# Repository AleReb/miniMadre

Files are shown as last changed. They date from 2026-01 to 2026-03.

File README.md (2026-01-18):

# miniMadre

**Placa de desarrollo basada en el trabajo de Sebastian Adonay con Alejandro Rebolledo.**

## Descripción del Proyecto

El objetivo de este proyecto es desarrollar una versión miniatura y flexible de una placa madre (*motherboard*) que también funcione como una placa para el **hiriPro**.

### Características Principales

*   **Versatilidad:** Diseñada para ser una solución miniatura y flexible.
*   **Integración ESP32-S3:** Se remplaza el uso de chips FTDI por el uso directo del **ESP32-S3**, aprovechando sus capacidades nativas de USB y mayor potencia de procesamiento.
*   **Expansión Flexible:** Incorpora un conector flexible diseñado específicamente para sacar placas hijo (*daughter boards*), permitiendo una gran modularidad y adaptabilidad a diferentes proyectos.

---
*Este proyecto es una evolución colaborativa buscando optimizar espacio y funcionalidad.*

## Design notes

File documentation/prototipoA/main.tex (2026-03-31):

\documentclass[9pt,a4paper,twocolumn,twoside]{rho-class/rho}

\usepackage[english]{babel}
\usepackage[utf8]{inputenc}
\usepackage[T1]{fontenc}
\usepackage{booktabs}
\usepackage{algorithm}
\usepackage{algpseudocode}
\usepackage{pgfplots}
\usepackage{tikz}
\usepackage{float}
\usepackage{comment}
\usepackage{hyperref}
\usepackage{array}

\usetikzlibrary{shapes.geometric, arrows.meta, positioning}
\tikzset{
    flow/.style={node distance=0.75cm, every node/.style={font=\footnotesize}},
    startstop/.style={rectangle, rounded corners, minimum width=1.8cm, minimum height=0.5cm, draw, align=center},
    process/.style={rectangle, minimum width=2.2cm, minimum height=0.5cm, draw, align=center},
    decision/.style={diamond, aspect=2, draw, align=center, inner sep=1pt, text width=2.0cm},
    arrow/.style={thick, -{Latex[length=2mm]}}
}

\doctype{Reporte de Diseño}
\title{Documentación de decisiones de diseño para asignación de pines y control de alimentación en "Placa Madre Mini"}

\author[{\textasteriskcentered},a]{Adonay, Sebastián}
\affil[a]{Centro de Investigación en Tecnologías para la Sociedad C+, Universidad del Desarrollo}
\dates{Este manuscrito ha sido compilado el \today}

\corres{\textsuperscript{\textasteriskcentered}Autor correspondiente: \href{mailto:s.adonay@udd.cl}{s.adonay@udd.cl} (S. Adonay).}

\docinfo{Documento interno de apoyo al diseño electrónico y firmware.}

\journalname{Documentación Interna}
\journal{C+ UDD 2026}
\theday{\today}

\begin{abstract}
Se documentan las principales decisiones de diseño adoptadas para la asignación de pines de una placa basada en ESP32-S3-WROOM-1, incluyendo buses de comunicación, expansión mediante conector IDC, medición de batería, control de NeoPixel y manejo de rieles de alimentación conmutables para periféricos y módem. Además, se explicita la justificación para reservar ciertos GPIO y se resume el pinout global e interfaz de expansión.
\end{abstract}

\keywords{ESP32-S3, Pinout, GPIO, I2C, SPI, UART, NeoPixel, Power Gating, SIM7600, IDC}

\begin{document}

\maketitle
\thispagestyle{firststyle}

\section{Introducción}

\rhostart{E}l presente documento resume las decisiones de diseño adoptadas para una placa basada en \textbf{ESP32-S3-WROOM-1}, con énfasis en la asignación funcional de pines, la segregación de rieles de alimentación y la exposición de señales hacia un conector de expansión IDC.

El objetivo principal fue construir una arquitectura ordenada y mantenible, adecuada tanto para desarrollo de firmware como para revisión de hardware, evitando conflictos con pines sensibles de arranque, USB nativo y señales con restricciones funcionales.

\section{Descripción general del sistema}

La arquitectura considera tres rieles principales de interés:

\begin{itemize}
    \item \texttt{3V3}: riel principal siempre activo.
    \item \texttt{3V3\_INT}: riel 3.3V conmutable para periféricos generales y externos.
    \item \texttt{3V3\_MODEM}: riel 3.3V conmutable dedicado al módem.
    \item \texttt{5V\_INT}: riel 5.0V conmutable para sensor "Plantower" y periféricos externos.
\end{itemize}

El microcontrolador mantiene alimentación permanente, mientras que periféricos de mayor consumo o de operación intermitente se energizan selectivamente mediante MOSFET P-channel en configuración \textit{high-side}.

\section{Decisiones de diseño}

\subsection{Buses por defecto}

Se decidió mantener los buses principales usando la asignación estándar del entorno Arduino IDE para la placa \texttt{ESP32S3 Dev Module}, con el fin de facilitar compatibilidad, depuración y legibilidad del firmware:

\begin{itemize}
    \item \textbf{I2C}: GPIO8 (SDA) y GPIO9 (SCL).
    \item \textbf{SPI}: GPIO10 (SS), GPIO11 (MOSI), GPIO12 (SCK) y GPIO13 (MISO).
\end{itemize}

En el caso particular del conector IDC, la señal \texttt{SS} no fue exportada, debido a que la tarjeta SD reside en la placa principal y utiliza localmente dicha línea.

\newpage

\subsection{UARTs}

Se reservaron UARTs diferenciadas para propósitos distintos:

\begin{itemize}
    \item UART auxiliar en GPIO4 y GPIO5, conectado a conector "Plantower"
    \item UART dedicada al módem en GPIO15 y GPIO16.
    \item UART0 de programación y depuración en GPIO43 y GPIO44.
\end{itemize}

\subsection{Medición de batería}

La medición analógica del voltaje de batería se fijó en \textbf{GPIO1}, correspondiente a un canal ADC válido del ESP32-S3.

\subsection{NeoPixel}

La señal de control del NeoPixel se asignó a \textbf{GPIO14}. Este pin también se mantuvo disponible en el conector IDC, permitiendo flexibilidad de uso futuro.

\subsection{Power gating}

Se adoptó control de rieles mediante MOSFET P-channel:\\
\textbf{Nota: los controles de gate 3v3 y modem se activan en LOW y el de 5v en HIGH}
\begin{itemize}
    \item \textbf{GPIO41}: control de \texttt{Gate\_3V3INT}.
    \item \textbf{GPIO42}: control de \texttt{Gate\_MODEM}.
\end{itemize}

La conmutación se realiza por el lado alto (\textit{high-side}), evitando corte de GND y reduciendo riesgos de retroalimentación a través de interfaces lógicas.

A su vez, el riel de 5V se activa al entregar voltaje al pin ENABLE del regulador AP63357 de 5V.
\begin{itemize}
    \item \textbf{GPIO2}: control de \texttt{EN\_5V\_INT}.
\end{itemize}

\subsection{Pines reservados o evitados}

Se decidió evitar o reservar los siguientes GPIO por su naturaleza funcional:

\begin{itemize}
    \item GPIO0 y GPIO3: pines de \textit{strapping}.
    \item GPIO19 y GPIO20: USB nativo.
    \item GPIO45: pin de \textit{strapping}.
    \item GPIO46: pin de entrada solamente, además de \textit{strapping}.
\end{itemize}

\newpage

\section{Asignación por categoría}

\begin{table}[H]
\centering
\resizebox{0.55\columnwidth}{!}{
\begin{tabular}{ccl}
\toprule
\textbf{GPIO} & \textbf{Categoría} & \textbf{Función} \\
\midrule
\multicolumn{3}{l}{\textbf{I2C}} \\
\midrule
8  & I2C   & SDA \\
9  & I2C   & SCL \\

\midrule
\multicolumn{3}{l}{\textbf{SPI / SD}} \\
\midrule
10 & SPI   & SS (SD en placa principal) \\
11 & SPI   & MOSI \\
12 & SPI   & SCK \\
13 & SPI   & MISO \\

\midrule
\multicolumn{3}{l}{\textbf{UART}} \\
\midrule
4  & UART  & RX auxiliar \\
5  & UART  & TX auxiliar \\
15 & UART  & RX módem \\
16 & UART  & TX módem \\
43 & UART  & TX0 (debug) \\
44 & UART  & RX0 (debug) \\

\midrule
\multicolumn{3}{l}{\textbf{ADC}} \\
\midrule
1  & ADC   & Medición de batería \\

\midrule
\multicolumn{3}{l}{\textbf{Power Control}} \\
\midrule
2 & Power & \texttt{EN\_5V\_INT} \\
41 & Power & \texttt{Gate\_3V3\_INT} \\
42 & Power & \texttt{Gate\_MODEM} \\

\midrule
\multicolumn{3}{l}{\textbf{NeoPixel}} \\
\midrule
14 & LED   & Data NeoPixel \\

\midrule
\multicolumn{3}{l}{\textbf{Expansión (IDC)}} \\
\midrule
14 & IDC   & GPIO expansión \\
21 & IDC   & GPIO expansión \\
35 & IDC   & GPIO expansión \\
36 & IDC   & GPIO expansión \\
37 & IDC   & GPIO expansión \\
38 & IDC   & GPIO expansión \\
39 & IDC   & GPIO expansión \\
40 & IDC   & GPIO expansión \\
47 & IDC   & GPIO expansión \\
48 & IDC   & GPIO expansión \\

\midrule
\multicolumn{3}{l}{\textbf{Reservados / Evitados}} \\
\midrule
0  & Reserved & Strapping (boot) \\
3  & Reserved & Strapping (boot) \\
19 & Reserved & USB D- \\
20 & Reserved & USB D+ \\
45 & Reserved & Strapping \\
46 & Reserved & Input-only + strapping \\
\bottomrule
\end{tabular}
}
\caption{Asignación de pines agrupada por categoría}
\end{table}

\section{Asignación por Pin GPIO ESP32}

\begin{table}[H]
\centering
\resizebox{0.7\columnwidth}{!}{
\begin{tabular}{cll}
\toprule
\textbf{GPIO} & \textbf{Categoría} & \textbf{Función} \\
\midrule
0   & Strapping & No usar (boot)\\
1   & ADC & Lectura batería (ADC1\_CH0) \\
2   & Power Control & Pin Enable de StepDown $5V_{INT}$\\
3   & Strapping & No usar (boot)\\
4   & UART & RX auxiliar \\
5   & UART & TX auxiliar \\
6   & GPIO & Botón 1 \\
7   & GPIO & Botón 2 \\
8   & I2C & SDA \\
9   & I2C & SCL \\
10  & SPI & SS (SD en placa principal) \\
11  & SPI & MOSI \\
12  & SPI & SCK \\
13  & SPI & MISO \\
14  & GPIO / LED & NeoPixel (también exportado a IDC) \\
15  & UART & RX módem \\
16  & UART & TX módem \\
17  & GPIO (JST) & Expansión \\
18  & GPIO (JST) & Expansión \\
19  & USB D- & Pin D- de comunicación USB \\
20  & USB D+ & Pin D+ de comunicación USB \\
21  & GPIO (IDC) & Expansión \\
35  & GPIO (IDC) & Expansión \\
36  & GPIO (IDC) & Expansión \\
37  & GPIO (IDC) & Expansión \\
38  & GPIO (IDC) & Expansión \\
39  & GPIO (IDC) & Expansión \\
40  & GPIO (IDC) & Expansión \\
41  & Power Control & \texttt{Gate\_3V3INT} \\
42  & Power Control & \texttt{Gate\_MODEM} \\
43  & UART & TX0 (programación / debug) \\
44  & UART & RX0 (programación / debug) \\
45  & Strapping & No usar \\
46  & Strapping & No usar \\
47  & GPIO (IDC) & Expansión \\
48  & GPIO (IDC) & Expansión \\
\bottomrule
\end{tabular}
}
\caption{Asignación global de pines del sistema}
\label{tab:pinout_global}
\end{table}

\newpage%-------------------------------------------------\section{Asignación conectores}

\begin{table}[H]
\centering
\setlength{\tabcolsep}{4pt}
\begin{tabular}{cll}
\toprule
\textbf{Pin} & \textbf{Señal} & \textbf{Descripción} \\
\midrule

\multicolumn{3}{l}{\textbf{IDC-26 (J8)}} \\
\midrule
1  & \texttt{12V}     & Alimentación 12V \\
2  & \texttt{12V}     & Alimentación 12V \\
3  & \texttt{5V\_INT} & Alimentación 5V \\
4  & \texttt{5V\_INT} & Alimentación 5V \\
5  & \texttt{3V3\_INT} & Rail conmutable \\
6  & \texttt{3V3\_INT} & Rail conmutable \\
7  & \texttt{3V3}      & Rail principal \\
8  & \texttt{IO47}     & GPIO \\
9  & \texttt{IO21}     & GPIO \\
10 & \texttt{IO48}     & GPIO \\
11 & \texttt{IO14}     & GPIO / NeoPixel \\
12 & \texttt{IO35}     & GPIO \\
13 & \texttt{IO13}     & SPI MISO \\
14 & \texttt{IO36}     & GPIO \\
15 & \texttt{IO12}     & SPI SCK \\
16 & \texttt{IO37}     & GPIO \\
17 & \texttt{IO11}     & SPI MOSI \\
18 & \texttt{IO38}     & GPIO \\
19 & \texttt{IO9}      & I2C SCL \\
20 & \texttt{IO39}     & GPIO \\
21 & \texttt{IO8}      & I2C SDA \\
22 & \texttt{IO40}     & GPIO \\
23 & \texttt{GND}      & Tierra \\
24 & \texttt{GND}      & Tierra \\
25 & \texttt{GND}      & Tierra \\
26 & \texttt{GND}      & Tierra \\

\midrule
\multicolumn{3}{l}{\textbf{Plantower (J1)}} \\
\midrule
1 & \texttt{N/C} & --- \\
2 & \texttt{N/C} & --- \\
3 & \texttt{N/C} & --- \\
4 & \texttt{IO4} & UART RX \\
5 & \texttt{IO5} & UART TX \\
6 & \texttt{N/C} & --- \\
7 & \texttt{GND} & Tierra \\
8 & \texttt{5V\_INT} & Alimentación \\

\midrule
\multicolumn{3}{l}{\textbf{I2C (J2)}} \\
\midrule
1 & \texttt{GND} & Tierra \\
2 & \texttt{3V3\_INT} & Alimentación \\
3 & \texttt{IO9} & SCL \\
4 & \texttt{IO8} & SDA \\

\midrule
\multicolumn{3}{l}{\textbf{I2C (J3)}} \\
\midrule
1 & \texttt{GND} & Tierra \\
2 & \texttt{3V3\_INT} & Alimentación \\
3 & \texttt{IO9} & SCL \\
4 & \texttt{IO8} & SDA \\

\midrule
\multicolumn{3}{l}{\textbf{Botón (J4)}} \\
\midrule
1 & \texttt{GND} & Tierra \\
2 & \texttt{IO6} & Entrada botón \\

\midrule
\multicolumn{3}{l}{\textbf{Botón (J5)}} \\
\midrule
1 & \texttt{GND} & Tierra \\
2 & \texttt{IO7} & Entrada botón \\

\midrule
\multicolumn{3}{l}{\textbf{GPIO (J6)}} \\
\midrule
1 & \texttt{GND} & Tierra \\
2 & \texttt{3V3\_INT} & Alimentación \\
3 & \texttt{IO18} & GPIO \\
4 & \texttt{IO17} & GPIO \\

\midrule
\multicolumn{3}{l}{\textbf{NeoPixel (J7)}} \\
\midrule
1 & \texttt{GND} & Tierra \\
2 & \texttt{3V3} & Alimentación \\
3 & \texttt{IO14} & Data \\

\bottomrule
\end{tabular}
\caption{Resumen completo de conectores y pinout}
\end{table}

\printbibliography

\end{document}

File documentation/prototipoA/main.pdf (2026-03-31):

Reporte de Diseño

# Documentación de decisiones de diseño para asignación de pines y control de alimentación en "Placa Madre Mini"

Adonay, Sebastián*,a

aCentro de Investigación en Tecnologías para la Sociedad C+, Universidad del Desarrollo

Este manuscrito ha sido compilado el March 31, 2026

Abstract

Se documentan las principales decisiones de diseño adoptadas para la asignación de pines de una placa basada en ESP32-S3-WROOM-1, incluyendo buses de comunicación, expansión mediante conector IDC, medición de batería, control de NeoPixel y manejo de rieles de alimentación conmutables para periféricos y módem. Además, se explicita la justificación para reservar ciertos GPIO y se resume el pinout global e interfaz de expansión.

Keywords: ESP32-S3, Pinout, GPIO, I2C, SPI, UART, NeoPixel, Power Gating, SIM7600, IDC

### 1. INTRODUCCIÓN

E
l presente documento resume las decisiones de diseño adoptadas para una placa basada en ESP32-S3-WROOM-1, con énfasis en la asignación funcional de pines, la segregación de rieles de alimentación y la exposición de señales hacia un conector de expansión IDC.
El objetivo principal fue construir una arquitectura ordenada y mantenible, adecuada tanto para desarrollo de firmware como para revisión de hardware, evitando conflictos con pines sensibles de arranque, USB nativo y señales con restricciones funcionales.

### 2. DESCRIPCIÓN GENERAL DEL SISTEMA

La arquitectura considera tres rieles principales de interés:

- 3V3: riel principal siempre activo.
- 3V3_INT: riel 3.3V conmutable para periféricos generales y externos.
- 3V3_MODEM: riel 3.3V conmutable dedicado al módem.
- 5V_INT: riel 5.0V conmutable para sensor "Plantower" y periféricos externos.

El microcontrolador mantiene alimentación permanente, mientras que periféricos de mayor consumo o de operación intermitente se energizan selectivamente mediante MOSFET P-channel en configuración high-side.

### 3. DECISIONES DE DISEÑO

### 3.1. Buses por defecto

Se decidió mantener los buses principales usando la asignación estándar del entorno Arduino IDE para la placa ESP32S3 Dev Module, con el fin de facilitar compatibilidad, depuración y legibilidad del firmware:

- I2C: GPIO8 (SDA) y GPIO9 (SCL).
- SPI: GPIO10 (SS), GPIO11 (MOSI), GPIO12 (SCK) y GPIO13 (MISO).

En el caso particular del conector IDC, la señal SS no fue exportada, debido a que la tarjeta SD reside en la placa principal y utiliza localmente dicha línea.

### 3.2. UARTs

Se reservaron UARTs diferenciadas para propósitos distintos:

- UART auxiliar en GPIO4 y GPIO5, conectado a conector "Plantower"
- UART dedicada al módem en GPIO15 y GPIO16.
- UART0 de programación y depuración en GPIO43 y GPIO44.

### 3.3. Medición de batería

La medición analógica del voltaje de batería se fijó en GPIO1, correspondiente a un canal ADC válido del ESP32-S3.

### 3.4. NeoPixel

La señal de control del NeoPixel se asignó a GPIO14. Este pin también se mantuvo disponible en el conector IDC, permitiendo flexibilidad de uso futuro.

### 3.5. Power gating

Se adoptó control de rieles mediante MOSFET P-channel:
Nota: los controles de gate 3v3 y modem se activan en LOW y el de 5v en HIGH
- GPIO41: control de Gate_3V3INT.
- GPIO42: control de Gate_MODEM.

La conmutación se realiza por el lado alto (high-side), evitando corte de GND y reduciendo riesgos de retroalimentación a través de interfaces lógicas.
A su vez, el riel de 5V se activa al entregar voltaje al pin ENABLE del regulador AP63357 de 5V.
- GPIO2: control de EN_5V_INT.

### 3.6. Pines reservados o evitados

Se decidió evitar o reservar los siguientes GPIO por su naturaleza funcional:

- GPIO0 y GPIO3: pines de strapping.
- GPIO19 y GPIO20: USB nativo.
- GPIO45: pin de strapping.
- GPIO46: pin de entrada solamente, además de strapping.

*Autor correspondiente: s.adonay@udd.cl (S. Adonay).

Documento interno de apoyo al diseño electrónico y firmware.

Documentación Interna | March 31, 2026 | C+ UDD 2026 | 1–2

Documentación de decisiones de diseño para asignación de pines y control de alimentación en "Placa Madre Mini" | C+ UDD 2026

### 4. ASIGNACIÓN POR CATEGORÍA

GPIO | Categoría | Función

I2C

8 | I2C | SDA
9 | I2C | SCL
SPI / SD
10 | SPI | SS (SD en placa principal)
11 | SPI | MOSI
12 | SPI | SCK
13 | SPI | MISO
UART
4 | UART | RX auxiliar
5 | UART | TX auxiliar
15 | UART | RX módem
16 | UART | TX módem
43 | UART | TX0 (debug)
44 | UART | RX0 (debug)

ADC

1 | ADC | Medición de batería

Power Control

2 | Power | EN_5V_INT
41 | Power | Gate_3V3_INT
42 | Power | Gate_MODEM
NeoPixel
14 | LED | Data NeoPixel
Expansión (IDC)
14 | IDC | GPIO expansión
21 | IDC | GPIO expansión
35 | IDC | GPIO expansión
36 | IDC | GPIO expansión
37 | IDC | GPIO expansión
38 | IDC | GPIO expansión
39 | IDC | GPIO expansión
40 | IDC | GPIO expansión
47 | IDC | GPIO expansión
48 | IDC | GPIO expansión

Reservados / Evitados

0 | Reserved | Strapping (boot)
3 | Reserved | Strapping (boot)
19 | Reserved | USB D-
20 | Reserved | USB D+
45 | Reserved | Strapping
46 | Reserved | Input-only + strapping
Table 1. Asignación de pines agrupada por categoría

### 5. ASIGNACIÓN POR PIN GPIO ESP32

GPIO | Categoría | Función
0 | Strapping | No usar (boot)
1 | ADC | Lectura batería (ADC1_CH0)
2 | Power Control | Pin Enable de StepDown 5VINT
3 | Strapping | No usar (boot)
4 | UART | RX auxiliar
5 | UART | TX auxiliar
6 | GPIO | Botón 1
7 | GPIO | Botón 2
8 | I2C | SDA
9 | I2C | SCL
10 | SPI | SS (SD en placa principal)
11 | SPI | MOSI
12 | SPI | SCK
13 | SPI | MISO
14 | GPIO / LED | NeoPixel (también exportado a IDC)
15 | UART | RX módem
16 | UART | TX módem
17 | GPIO (JST) | Expansión
18 | GPIO (JST) | Expansión
19 | USB D- | Pin D- de comunicación USB
20 | USB D+ | Pin D+ de comunicación USB
21 | GPIO (IDC) | Expansión
35 | GPIO (IDC) | Expansión
36 | GPIO (IDC) | Expansión
37 | GPIO (IDC) | Expansión
38 | GPIO (IDC) | Expansión
39 | GPIO (IDC) | Expansión
40 | GPIO (IDC) | Expansión
41 | Power Control | Gate_3V3INT
42 | Power Control | Gate_MODEM
43 | UART | TX0 (programación / debug)
44 | UART | RX0 (programación / debug)
45 | Strapping | No usar
46 | Strapping | No usar
47 | GPIO (IDC) | Expansión
48 | GPIO (IDC) | Expansión
Table 2. Asignación global de pines del sistema

Pin Señal Descripción

IDC-26 (J8)

1 | 12V | Alimentación 12V
2 | 12V | Alimentación 12V
3 | 5V_INT | Alimentación 5V
4 | 5V_INT | Alimentación 5V
5 | 3V3_INT | Rail conmutable
6 | 3V3_INT | Rail conmutable
7 | 3V3 | Rail principal
8 | IO47 | GPIO
9 | IO21 | GPIO
10 | IO48 | GPIO
11 | IO14 | GPIO / NeoPixel
12 | IO35 | GPIO
13 | IO13 | SPI MISO
14 | IO36 | GPIO
15 | IO12 | SPI SCK
16 | IO37 | GPIO
17 | IO11 | SPI MOSI
18 | IO38 | GPIO
19 | IO9 | I2C SCL
20 | IO39 | GPIO
21 | IO8 | I2C SDA
22 | IO40 | GPIO
23 | GND | Tierra
24 | GND | Tierra
25 | GND | Tierra
26 | GND | Tierra
Plantower (J1)
1 | N/C | —
2 | N/C | —
3 | N/C | —
4 | IO4 | UART RX
5 | IO5 | UART TX
6 | N/C | —
7 | GND | Tierra
8 | 5V_INT | Alimentación
I2C (J2)
1 | GND | Tierra
2 | 3V3_INT | Alimentación
3 | IO9 | SCL
4 | IO8 | SDA
I2C (J3)
1 | GND | Tierra
2 | 3V3_INT | Alimentación
3 | IO9 | SCL
4 | IO8 | SDA
Botón (J4)
1 | GND | Tierra
2 | IO6 | Entrada botón
Botón (J5)
1 | GND | Tierra
2 | IO7 | Entrada botón
GPIO (J6)
1 | GND | Tierra
2 | 3V3_INT | Alimentación
3 | IO18 | GPIO
4 | IO17 | GPIO
NeoPixel (J7)
1 | GND | Tierra
2 | 3V3 | Alimentación
3 | IO14 | Data
Table 3. Resumen completo de conectores y pinout

2–2

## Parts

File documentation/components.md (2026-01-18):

# Component List - miniMadre PCB

This document lists the components identified in the `v1.sch` and `v1.brd` files of the `miniMadre` project.

## Integrated Circuits (ICs)

| Designator | Part Name | Description | Manufacturer | Datasheet |
| :--- | :--- | :--- | :--- | :--- |
| **U1** | TPS552892RYQR | 36-V, 8-A Buck-Boost Converter | Texas Instruments | [TPS552892 Datasheet](https://www.ti.com/product/TPS552892) |
| **NA** | ESP32-WROOM-32 S3 | Wi-Fi + BT + BLE MCU Module | Espressif Systems |[ESP32S3 datasheet](https://github.com/AleReb/miniMadre/blob/main/documentation/datasheets/esp32-s3-wroom-1_wroom-1u_datasheet_en.pdf)|
| **U4** | BQ24075RGTT | 1.5-A USB-Friendly Li-Ion Battery Charger | Texas Instruments | [BQ24075 Datasheet](https://www.ti.com/product/BQ24075) |
| **U6** | BQ27441DRZT | System-Side Impedance Track Fuel Gauge | Texas Instruments | [BQ27441-G1 Datasheet](https://www.ti.com/product/BQ27441-G1) |
| **IC1** | DS3231 | Extremely Accurate I2C-Integrated RTC/TCXO/Crystal | Maxim/Analog Devices | [DS3231 Datasheet](https://www.analog.com/media/en/technical-documentation/data-sheets/DS3231.pdf) |
| **U3** | FT232RL | USB to Serial UART Interface | FTDI | [FT232RL Datasheet](https://ftdichip.com/products/ft232rl/) |
| **Q1** | FS8205A | Dual N-Channel Enhancement Mode Power MOSFET | Fortune/Various | [FS8205A Datasheet](https://www.ic-fortune.com/) |
| **U2** | DW01A | Battery Protection IC | Fortune/Various | [DW01A Datasheet](https://www.ic-fortune.com/) |
| **Q2, Q3, Q4, Q5**| AO3404A / SI2300 | N-Channel MOSFET (Logic Level) | Alpha & Omega / Vishay | [AO3404A Datasheet](http://www.aosmd.com/res/data_sheets/AO3404A.pdf) |

## Connectors

| Designator | Part Number | Description | Manufacturer | Datasheet |
| :--- | :--- | :--- | :--- | :--- |
| **J1, J2, J3, J4, J5** | BM04B-SRSS-TB | 4-pin SH Connector, 1.0mm pitch, Top Entry | JST | [BM04B-SRSS-TB Datasheet](https://www.jst-mfg.com/product/pdf/eng/eSR.pdf) |
| **J6** | BM02B-SRSS-TB | 2-pin SH Connector, 1.0mm pitch, Top Entry | JST | [BM02B-SRSS-TB Datasheet](https://www.jst-mfg.com/product/pdf/eng/eSR.pdf) |
| **J7** | 53398-0871 | PicoBlade Header, 8 Ckt, 1.25mm pitch | Molex | [53398-0871 Datasheet](https://www.molex.com/molex/products/part-detail/pcb_headers/0533980871) |
| **J8** | USB4730 | USB Type-C Receptacle, IP67 | GCT | [USB4730 Datasheet](https://gct.co/connector/usb4730) |
| **J9** | 67910-0002 | Mini PCI Express Connector | Molex | [67910-0002 Datasheet](https://www.molex.com/molex/products/part-detail/memory_card_sockets/0679100002) |
| **J10 (Latch)** | 48099-4000 | Latch for Mini PCIe Card Holder | Molex | [48099-4000 Datasheet](https://www.molex.com/molex/products/part-detail/memory_card_sockets/0480994000) |
| **J11** | SIM8060 | SIM Card Holder | GCT/Various | - |
| **J13** | MEM2067 | Micro SD Card Holder | GCT/Various | - |
| **U$1** | B2B-PH-SM4-TB | PH Connector Header | JST | [PH Series Datasheet](https://www.jst-mfg.com/product/pdf/eng/ePH.pdf) |

## Passive Components (Selected)
*Note: Standard resistors and capacitors are listed with their values.*

| Components | Type | Package | Value/Description |
| :--- | :--- | :--- | :--- |
| **L1** | Inductor | 7045 | 1uH (MDH7045C-220MA family) |
| **C1, C2, C5, C6** | Capacitor | Aluminum / Tantalum | 100uF |
| **C7** | Capacitor | 0805 | 47uF |
| **C3, C15, C16, C29, C32** | Capacitor | 0805 | 10uF |
| **C9** | Capacitor | 0805 | 4.7uF |
| **C4, C8, C27, C31, C33** | Capacitor | 0805 | 1uF |
| **R1** | Resistor | 0805 | 48.7K |
| **R2, R3** | Resistor | 0805 | 102K |
| **R34** | Resistor | 1206 | 0.01R (Current Sense) |

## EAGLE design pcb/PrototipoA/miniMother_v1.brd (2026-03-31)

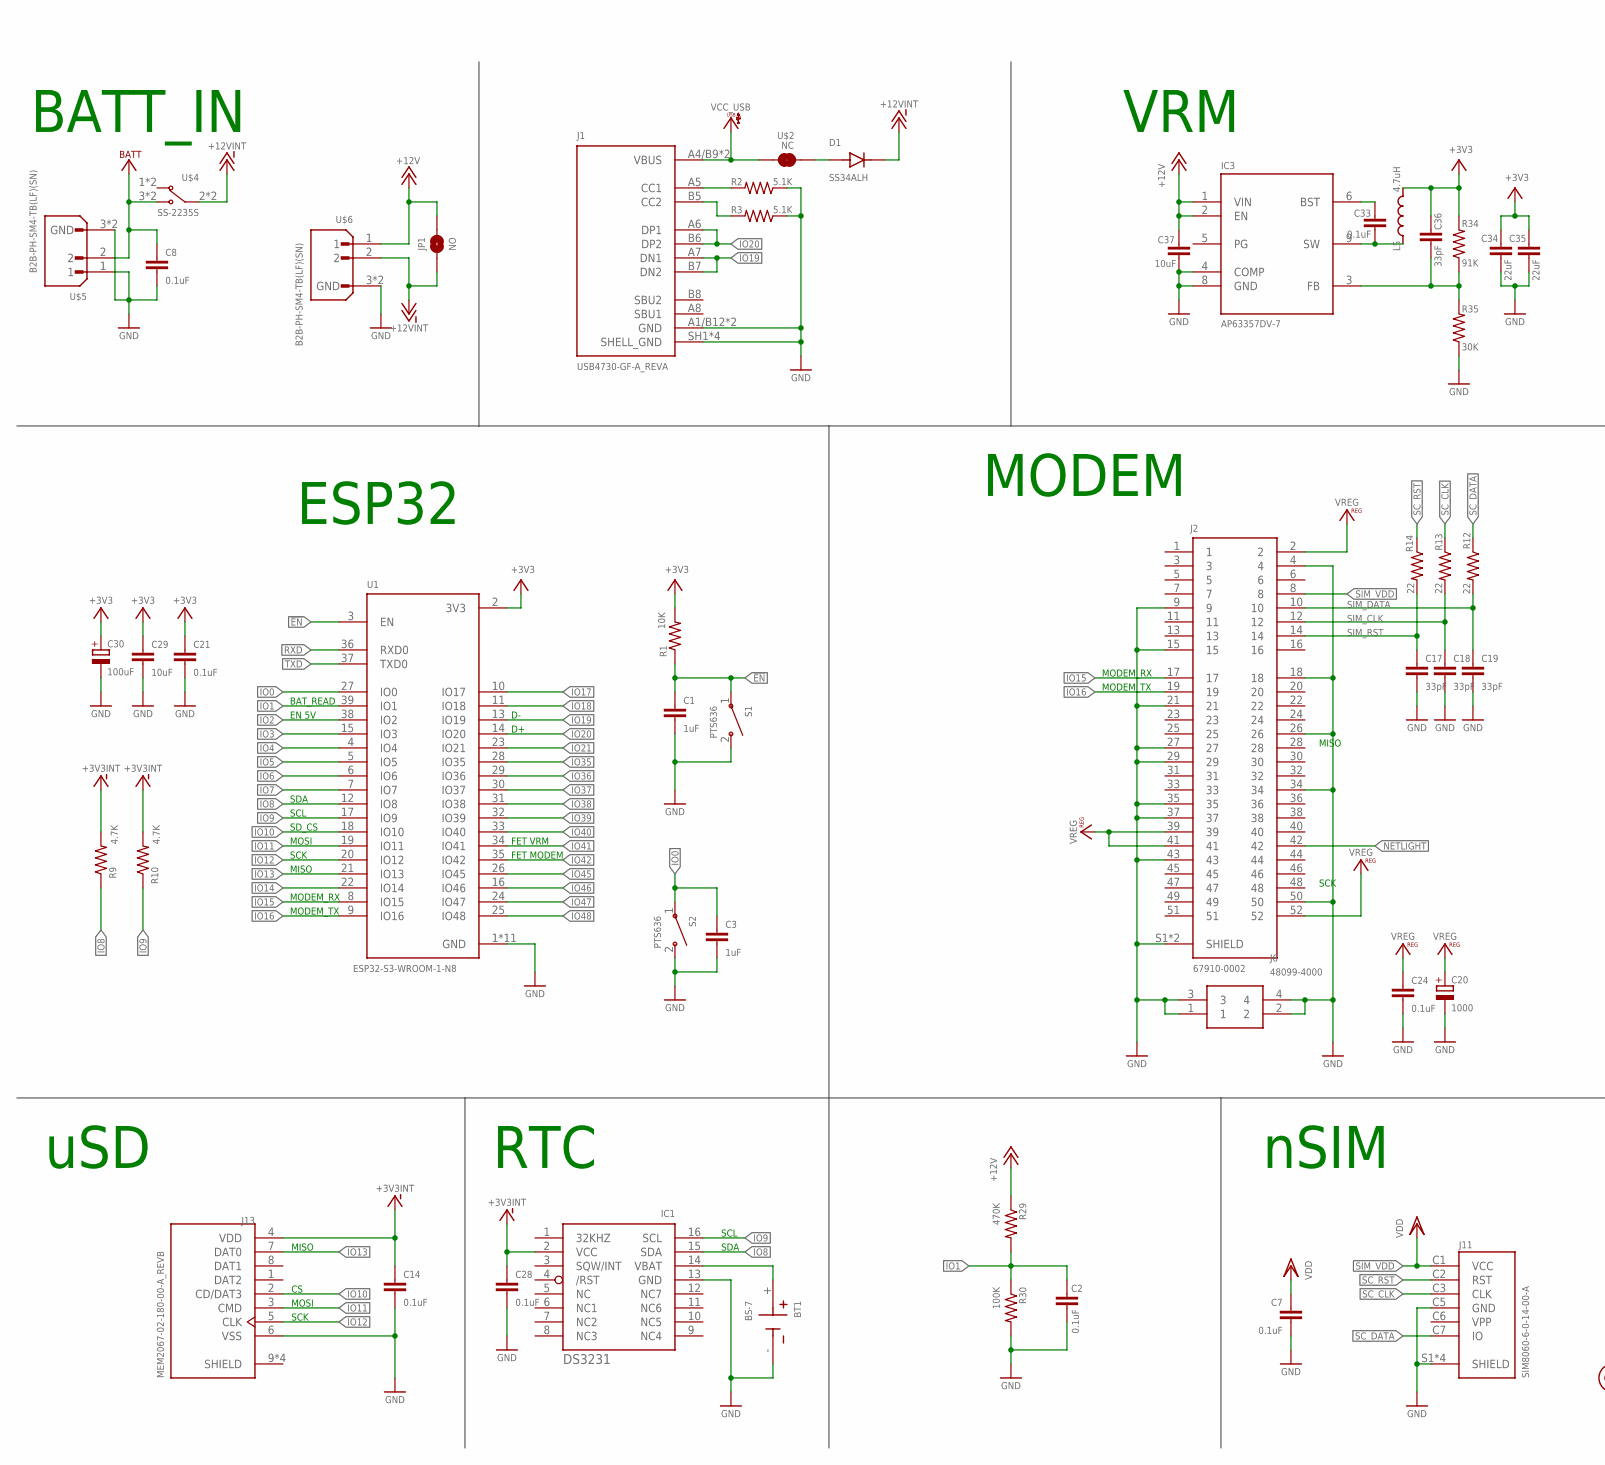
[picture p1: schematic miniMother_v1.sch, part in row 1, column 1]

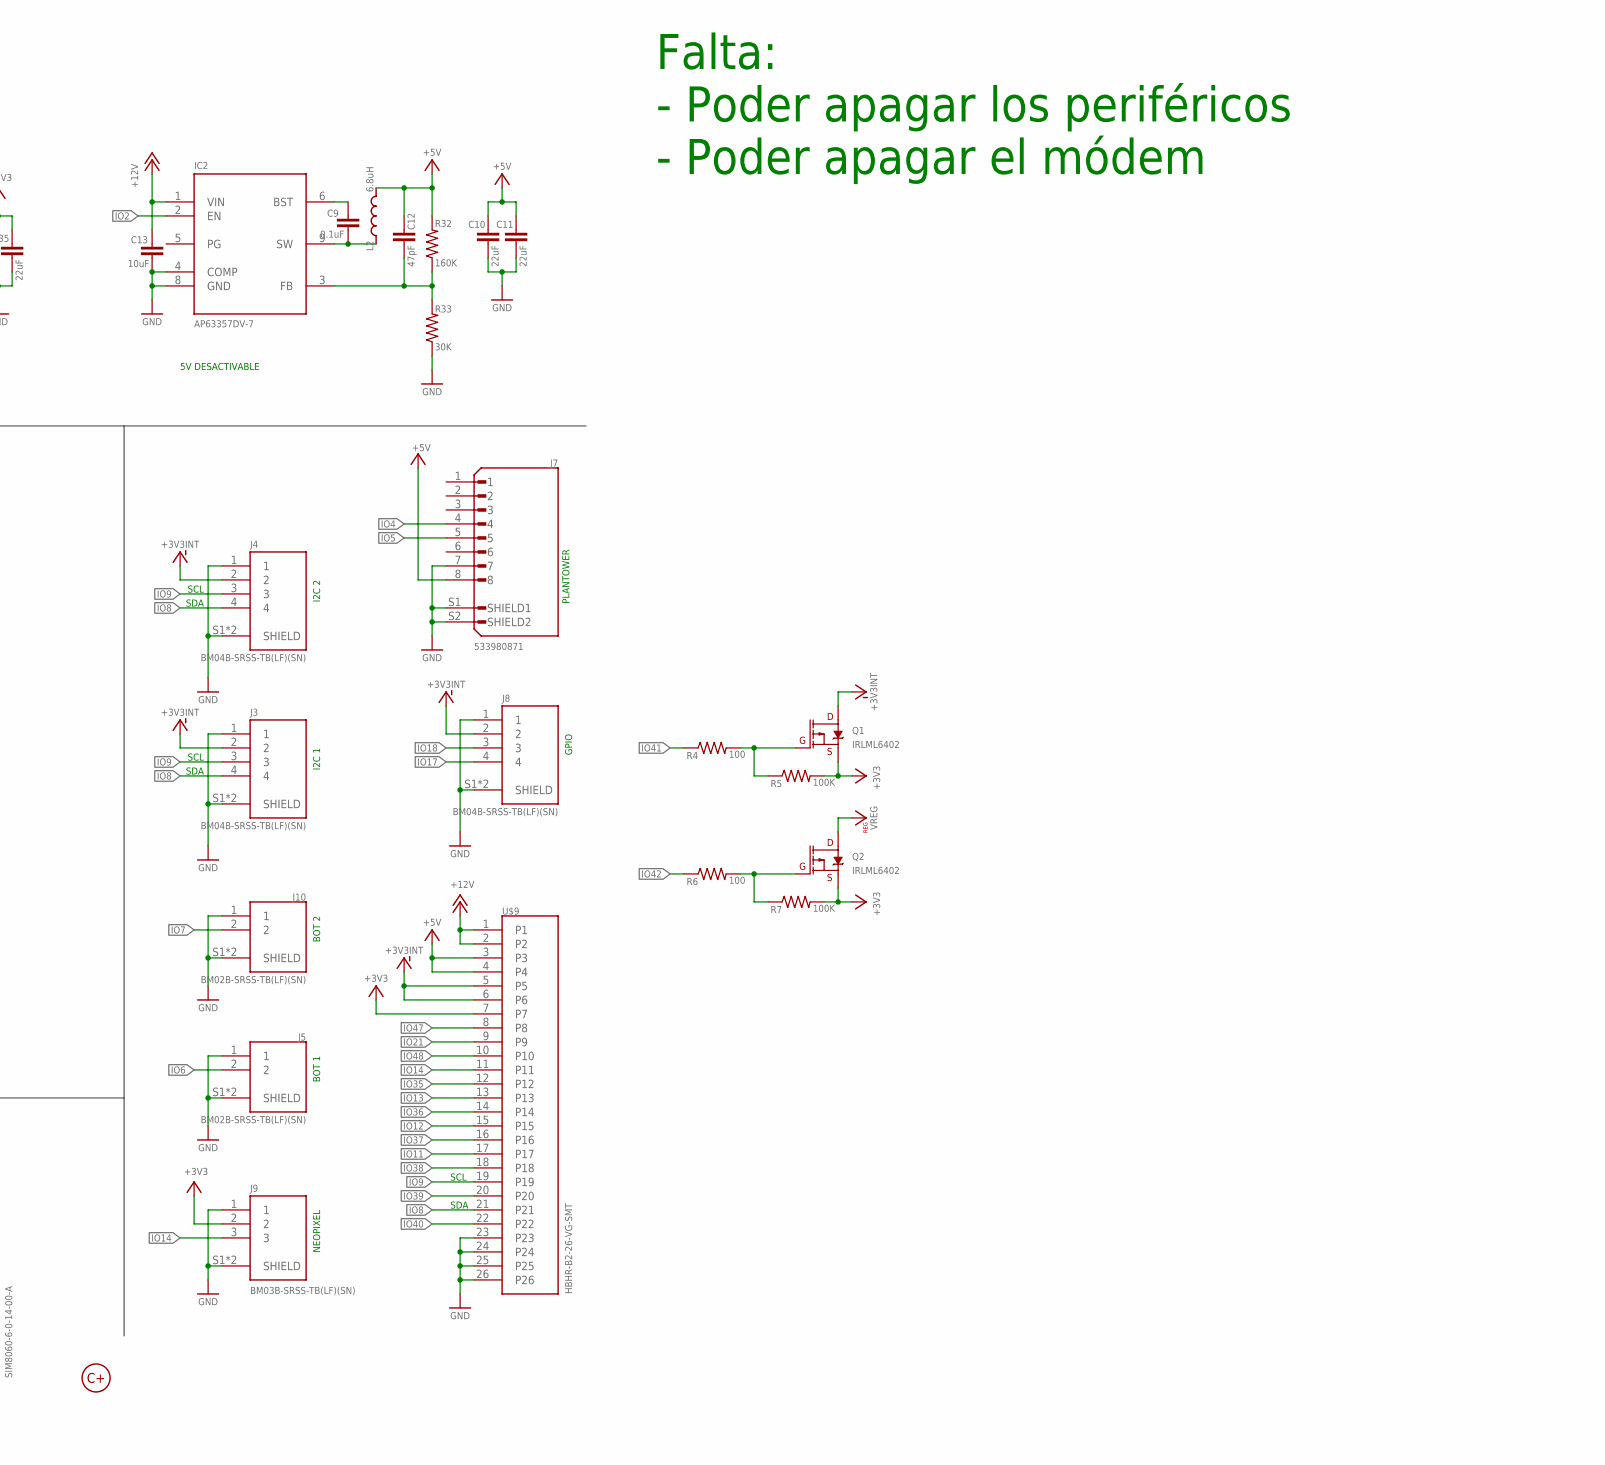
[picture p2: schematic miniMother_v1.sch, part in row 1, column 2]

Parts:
BT1: BS-7; BAT_BS-7
C1, C3: 1uF; C0805
C2, C7, C8, C9, C14, C21, C24, C28, C33: 0.1uF; C0805
C10, C11, C34, C35: 22uF; C0805
C12: 47pF; C0805
C13, C29, C37: 10uF; C0805
C17, C18, C19, C36: 33pF; C0805
C20: 1000; SMC_D
C30: 100uF; CT3528
D1: SS34ALH; SODFL5226X100N
IC1: DS3231/SO; SO16W
IC2, IC3: AP63357DV-7; AP63357DV7
J1: USB4730-GF-A_REVA; GCT_USB4730-GF-A_REVA
J2: 67910-0002; MOLEX_67910-0002
J3, J4, J8: BM04B-SRSS-TB(LF)(SN); JST_BM04B-SRSS-TB(LF)(SN)
J5, J10: BM02B-SRSS-TB(LF)(SN); JST_BM02B-SRSS-TB(LF)(SN)
J6: 48099-4000; 480994000
J7: 533980871; MOLEX_533980871
J9: BM03B-SRSS-TB(LF)(SN); JST_BM03B-SRSS-TB(LF)(SN)
J11: SIM8060-6-0-14-00-A; GCT_SIM8060-6-0-14-00-A
J13: MEM2067-02-180-00-A_REVB; GCT_MEM2067-02-180-00-A_REVB
JP1: NO; SMT-JUMPER_2_NO_NO-SILK_ROUND
L2: 6.8uH; IND_MDH7045C-220MA=P3
L5: 4.7uH; IND_MDH7045C-220MA=P3
Q1, Q2: IRLML6402; SOT23-3
R1: 10K; R0805
R2, R3: 5.1K; R0805
R4, R6: 100; R0805
R5, R7, R30: 100K; R0805
R9, R10: 4.7K; R0805
R12, R13, R14: 22; R0805
R29: 470K; R0805
R32: 160K; R0805
R33, R35: 30K; R0805
R34: 91K; R0805
S1, S2: PTS636; SW_PTS636_SM43J_SMTR_LFS
U1: ESP32-S3-WROOM-1-N8; XCVR_ESP32-S3-WROOM-1-N8
U$1: LOGO_CMAS10MM; LOGO_10MM
U$2: NC; SMT-JUMPER-2_NC
U$4: SS-2235S
U$5, U$6: B2B-PH-SM4-TB(LF)(SN); JST_B2B-PH-SM4-TB(LF)(SN)
U$9: HBHR-B2-26-VG-SMT

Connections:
!EN: C1.1, R1.1, S1.1 (COM), U1.3 (EN)
+3V3: C21.1, C29.1, C30.+, C34.1, C35.1, C36.1, J9.2, L5.2, Q1.2 (S), Q2.2 (S), R1.2, R5.2, R7.2, R34.2, U1.2 (3V3), U$9.7
+3V3INT: C14.1, C28.1, IC1.2 (VCC), J3.2, J4.2, J8.2, J13.4 (VDD), Q1.3 (D), R9.2, R10.2, U$9.5, U$9.6
+5V: C10.1, C11.1, C12.1, J7.8, L2.2, R32.2, U$9.3, U$9.4
+12V: C13.1, C37.1, IC2.1 (VIN), IC3.1 (VIN), IC3.2 (EN), JP1.1, R29.1, U$6.1, U$9.1, U$9.2
+12VINT: D1.1 (K), JP1.2, U$4.2 (P1), U$4.5 (P1), U$6.2
GND: BT1.-, C1.2, C2.2, C3.2, C7.2, C8.2, C10.2, C11.2, C13.2, C14.2, C17.2, C18.2, C19.2, C20.-, C21.2, C24.2, C28.2, C29.2, C30.-, C34.2, C35.2, C37.2, IC1.13 (GND), IC2.4 (COMP), IC2.8 (GND), IC3.4 (COMP), IC3.8 (GND), J1.A1/B12 (GND), J1.B1/A12 (GND), J1.SH1 (SHELL_GND), J1.SH2 (SHELL_GND), J1.SH3 (SHELL_GND), J1.SH4 (SHELL_GND), J2.4, J2.9, J2.15, J2.18, J2.21, J2.26, J2.27, J2.29, J2.34, J2.35, J2.37, J2.43, J2.50, J2.S1 (SHIELD), J2.S2 (SHIELD), J3.1, J3.S1 (SHIELD), J3.S2 (SHIELD), J4.1, J4.S1 (SHIELD), J4.S2 (SHIELD), J5.1, J5.S1 (SHIELD), J5.S2 (SHIELD), J6.1, J6.2, J6.3, J6.4, J7.7, J7.S1 (SHIELD1), J7.S2 (SHIELD2), J8.1, J8.S1 (SHIELD), J8.S2 (SHIELD), J9.1, J9.S1 (SHIELD), J9.S2 (SHIELD), J10.1, J10.S1 (SHIELD), J10.S2 (SHIELD), J11.C5 (GND), J11.S1 (SHIELD), J11.S2 (SHIELD), J11.S3 (SHIELD), J11.S4 (SHIELD), J13.6 (VSS), R2.1, R3.1, R30.2, R33.1, R35.1, S1.2 (NO), S2.2 (NO), U1.1 (GND), U1.40 (GND), U1.41_1 (GND), U1.41_2 (GND), U1.41_3 (GND), U1.41_4 (GND), U1.41_5 (GND), U1.41_6 (GND), U1.41_7 (GND), U1.41_8 (GND), U1.41_9 (GND), U$5.1, U$5.3 (GND), U$5.4 (GND), U$6.3 (GND), U$6.4 (GND), U$9.23, U$9.24, U$9.25, U$9.26
IO0: C3.1, S2.1 (COM), U1.27 (IO0)
IO1: C2.1, R29.2, R30.1, U1.39 (IO1)
IO2: IC2.2 (EN), U1.38 (IO2)
IO3: U1.15 (IO3)
IO4: J7.4, U1.4 (IO4)
IO5: J7.5, U1.5 (IO5)
IO6: J5.2, U1.6 (IO6)
IO7: J10.2, U1.7 (IO7)
IO8: IC1.15 (SDA), J3.4, J4.4, R9.1, U1.12 (IO8), U$9.21
IO9: IC1.16 (SCL), J3.3, J4.3, R10.1, U1.17 (IO9), U$9.19
IO10: J13.2 (CD/DAT3), U1.18 (IO10)
IO11: J13.3 (CMD), U1.19 (IO11), U$9.17
IO12: J13.5 (CLK), U1.20 (IO12), U$9.15
IO13: J13.7 (DAT0), U1.21 (IO13), U$9.13
IO14: J9.3, U1.22 (IO14), U$9.11
IO15: J2.17, U1.8 (IO15)
IO16: J2.19, U1.9 (IO16)
IO17: J8.4, U1.10 (IO17)
IO18: J8.3, U1.11 (IO18)
IO19: J1.A7 (DN1), J1.B7 (DN2), U1.13 (IO19)
IO20: J1.A6 (DP1), J1.B6 (DP2), U1.14 (IO20)
IO21: U1.23 (IO21), U$9.9
IO35: U1.28 (IO35), U$9.12
IO36: U1.29 (IO36), U$9.14
IO37: U1.30 (IO37), U$9.16
IO38: U1.31 (IO38), U$9.18
IO39: U1.32 (IO39), U$9.20
IO40: U1.33 (IO40), U$9.22
IO41: R4.1, U1.34 (IO41)
IO42: R6.1, U1.35 (IO42)
IO45: U1.26 (IO45)
IO46: U1.16 (IO46)
IO47: U1.24 (IO47), U$9.8
IO48: U1.25 (IO48), U$9.10
unnamed: J1.A5 (CC1), R2.2
unnamed: BT1.+, IC1.14 (VBAT)
unnamed: D1.2 (A), U$2.2
unnamed: Q1.1 (G), R4.2, R5.1
unnamed: J1.B5 (CC2), R3.2
unnamed: Q2.1 (G), R6.2, R7.1
unnamed: C9.1, IC2.6 (BST)
unnamed: C9.2, IC2.9 (SW), L2.1
unnamed: C12.2, IC2.3 (FB), R32.1, R33.2
unnamed: C33.1, IC3.6 (BST)
unnamed: C33.2, IC3.9 (SW), L5.1
unnamed: C36.2, IC3.3 (FB), R34.1, R35.2
NETLIGHT: J2.42
RXD: U1.36 (RXD0)
SC_CLK: J11.C3 (CLK), R13.1
SC_DATA: J11.C7 (IO), R12.1
SC_RST: J11.C2 (RST), R14.1
SIM_CLK: C18.1, J2.12, R13.2
SIM_DATA: C19.1, J2.10, R12.2
SIM_RST: C17.1, J2.14, R14.2
SIM_VDD: C7.1, J2.8, J11.C1 (VCC)
TXD: U1.37 (TXD0)
VBAT: C8.1, U$4.3 (T2), U$4.6 (T2), U$5.2
VCC_USB: J1.A4/B9 (VBUS), J1.B4/A9 (VBUS), U$2.1
VREG: C20.+, C24.1, J2.2, J2.39, J2.41, J2.52, Q2.3 (D)

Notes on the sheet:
VRM
MODEM
ESP32
RTC
nSIM
uSD
BATT_IN
5V DESACTIVABLE
MOSI
SCK
MISO
PLANTOWER
Falta: - Poder apagar los periféricos - Poder apagar el módem
I2C 1
I2C 2
BOT 1
BOT 2
NEOPIXEL
GPIO
SDA
SCL
SD_CS
MODEM_RX
MODEM_TX
EN 5V
BAT_READ
FET VRM
FET MODEM

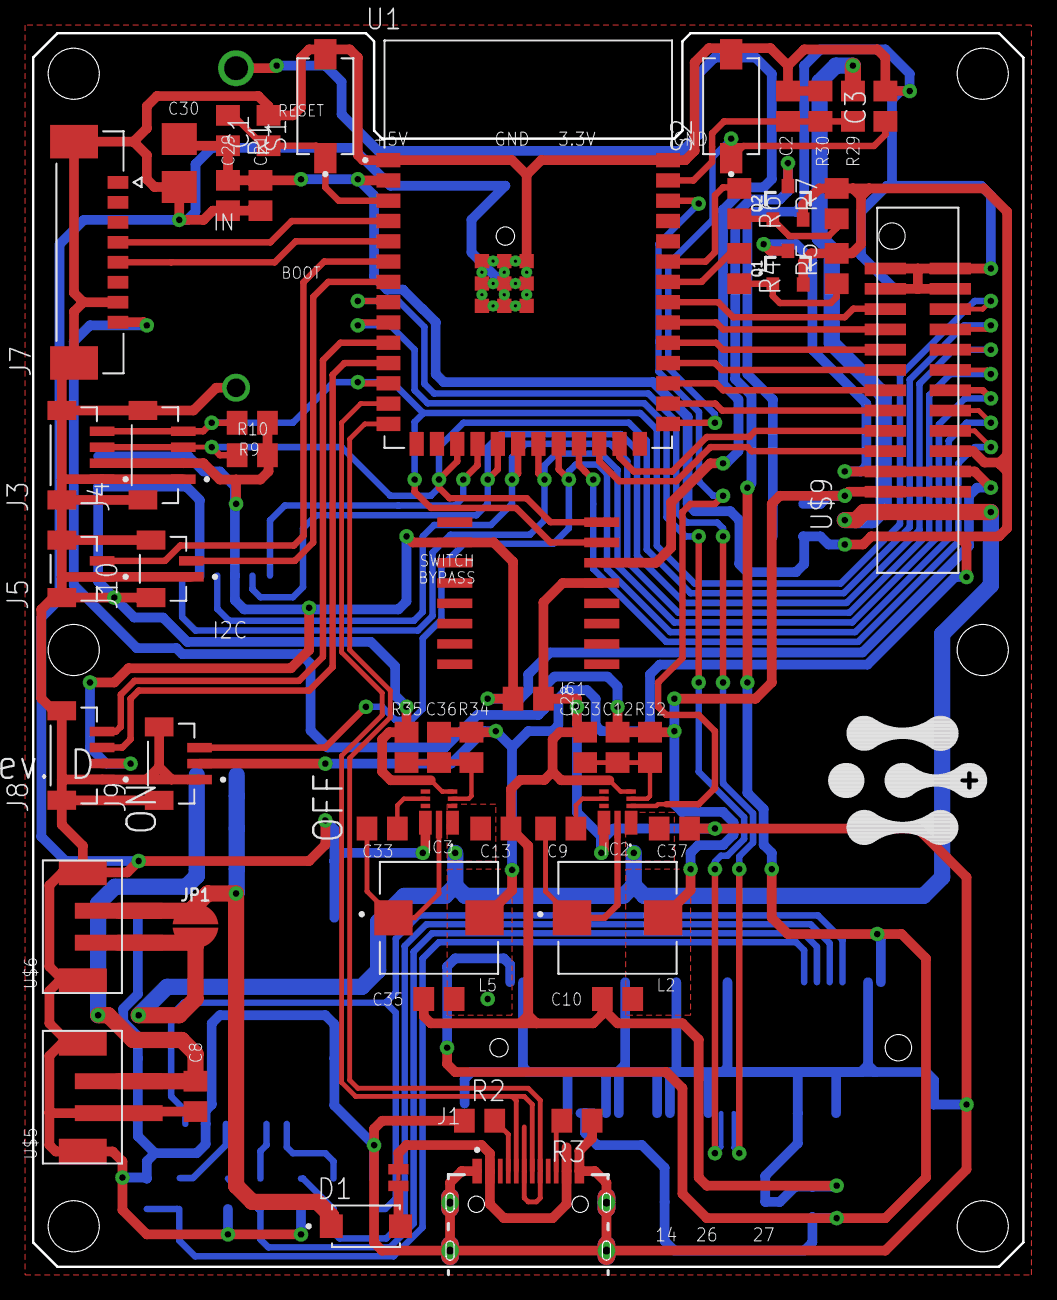
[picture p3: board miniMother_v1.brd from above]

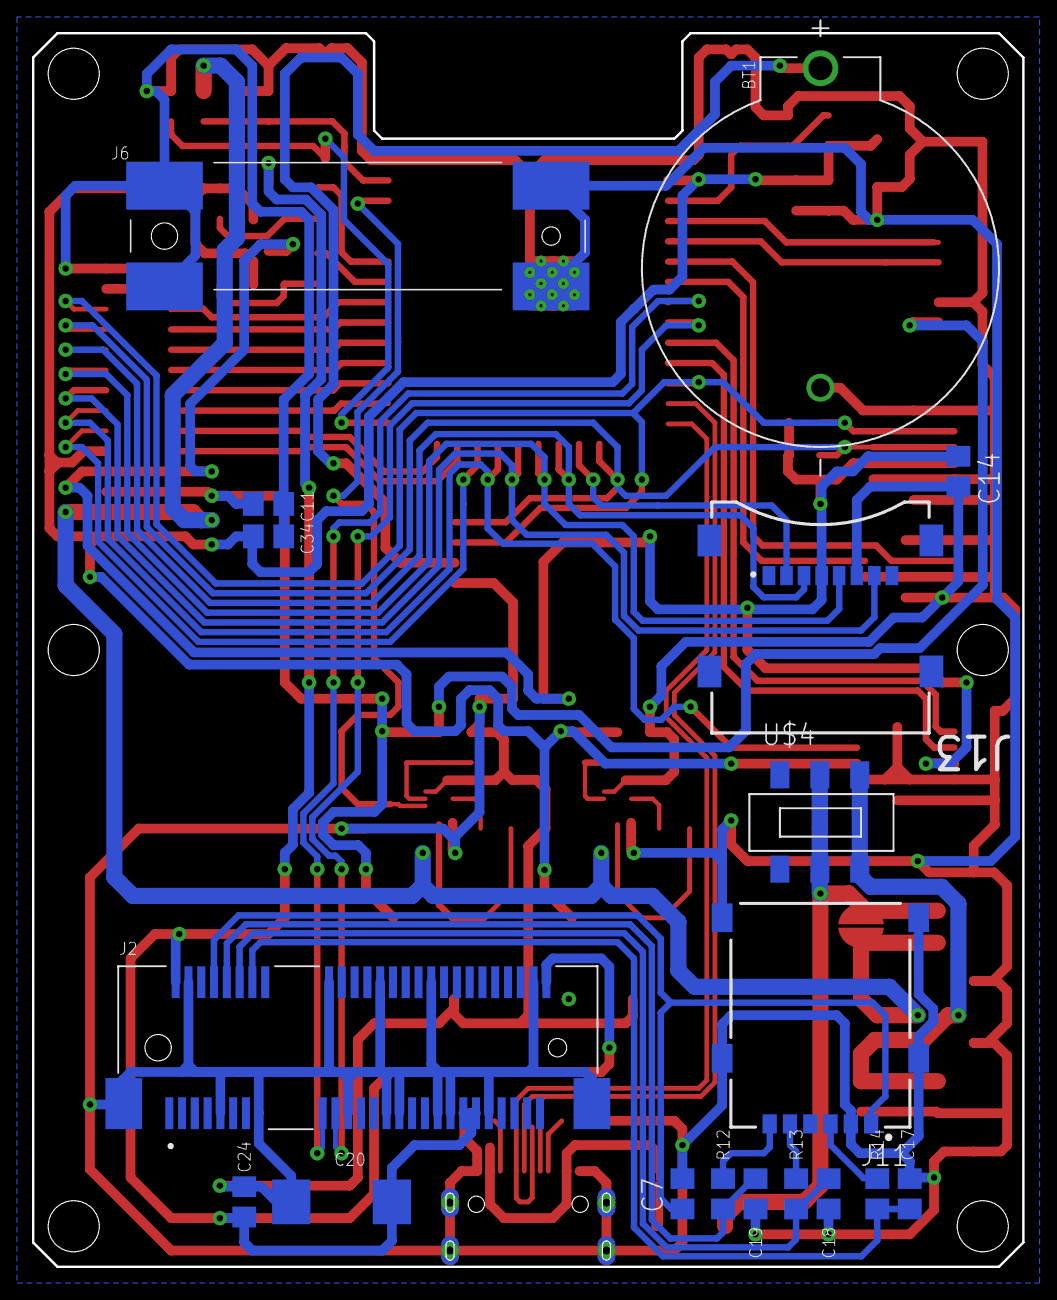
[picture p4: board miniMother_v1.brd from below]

Board: 2 copper layers, 62.0 x 77.2 mm, 74 parts (18 on the bottom side), 60 nets.

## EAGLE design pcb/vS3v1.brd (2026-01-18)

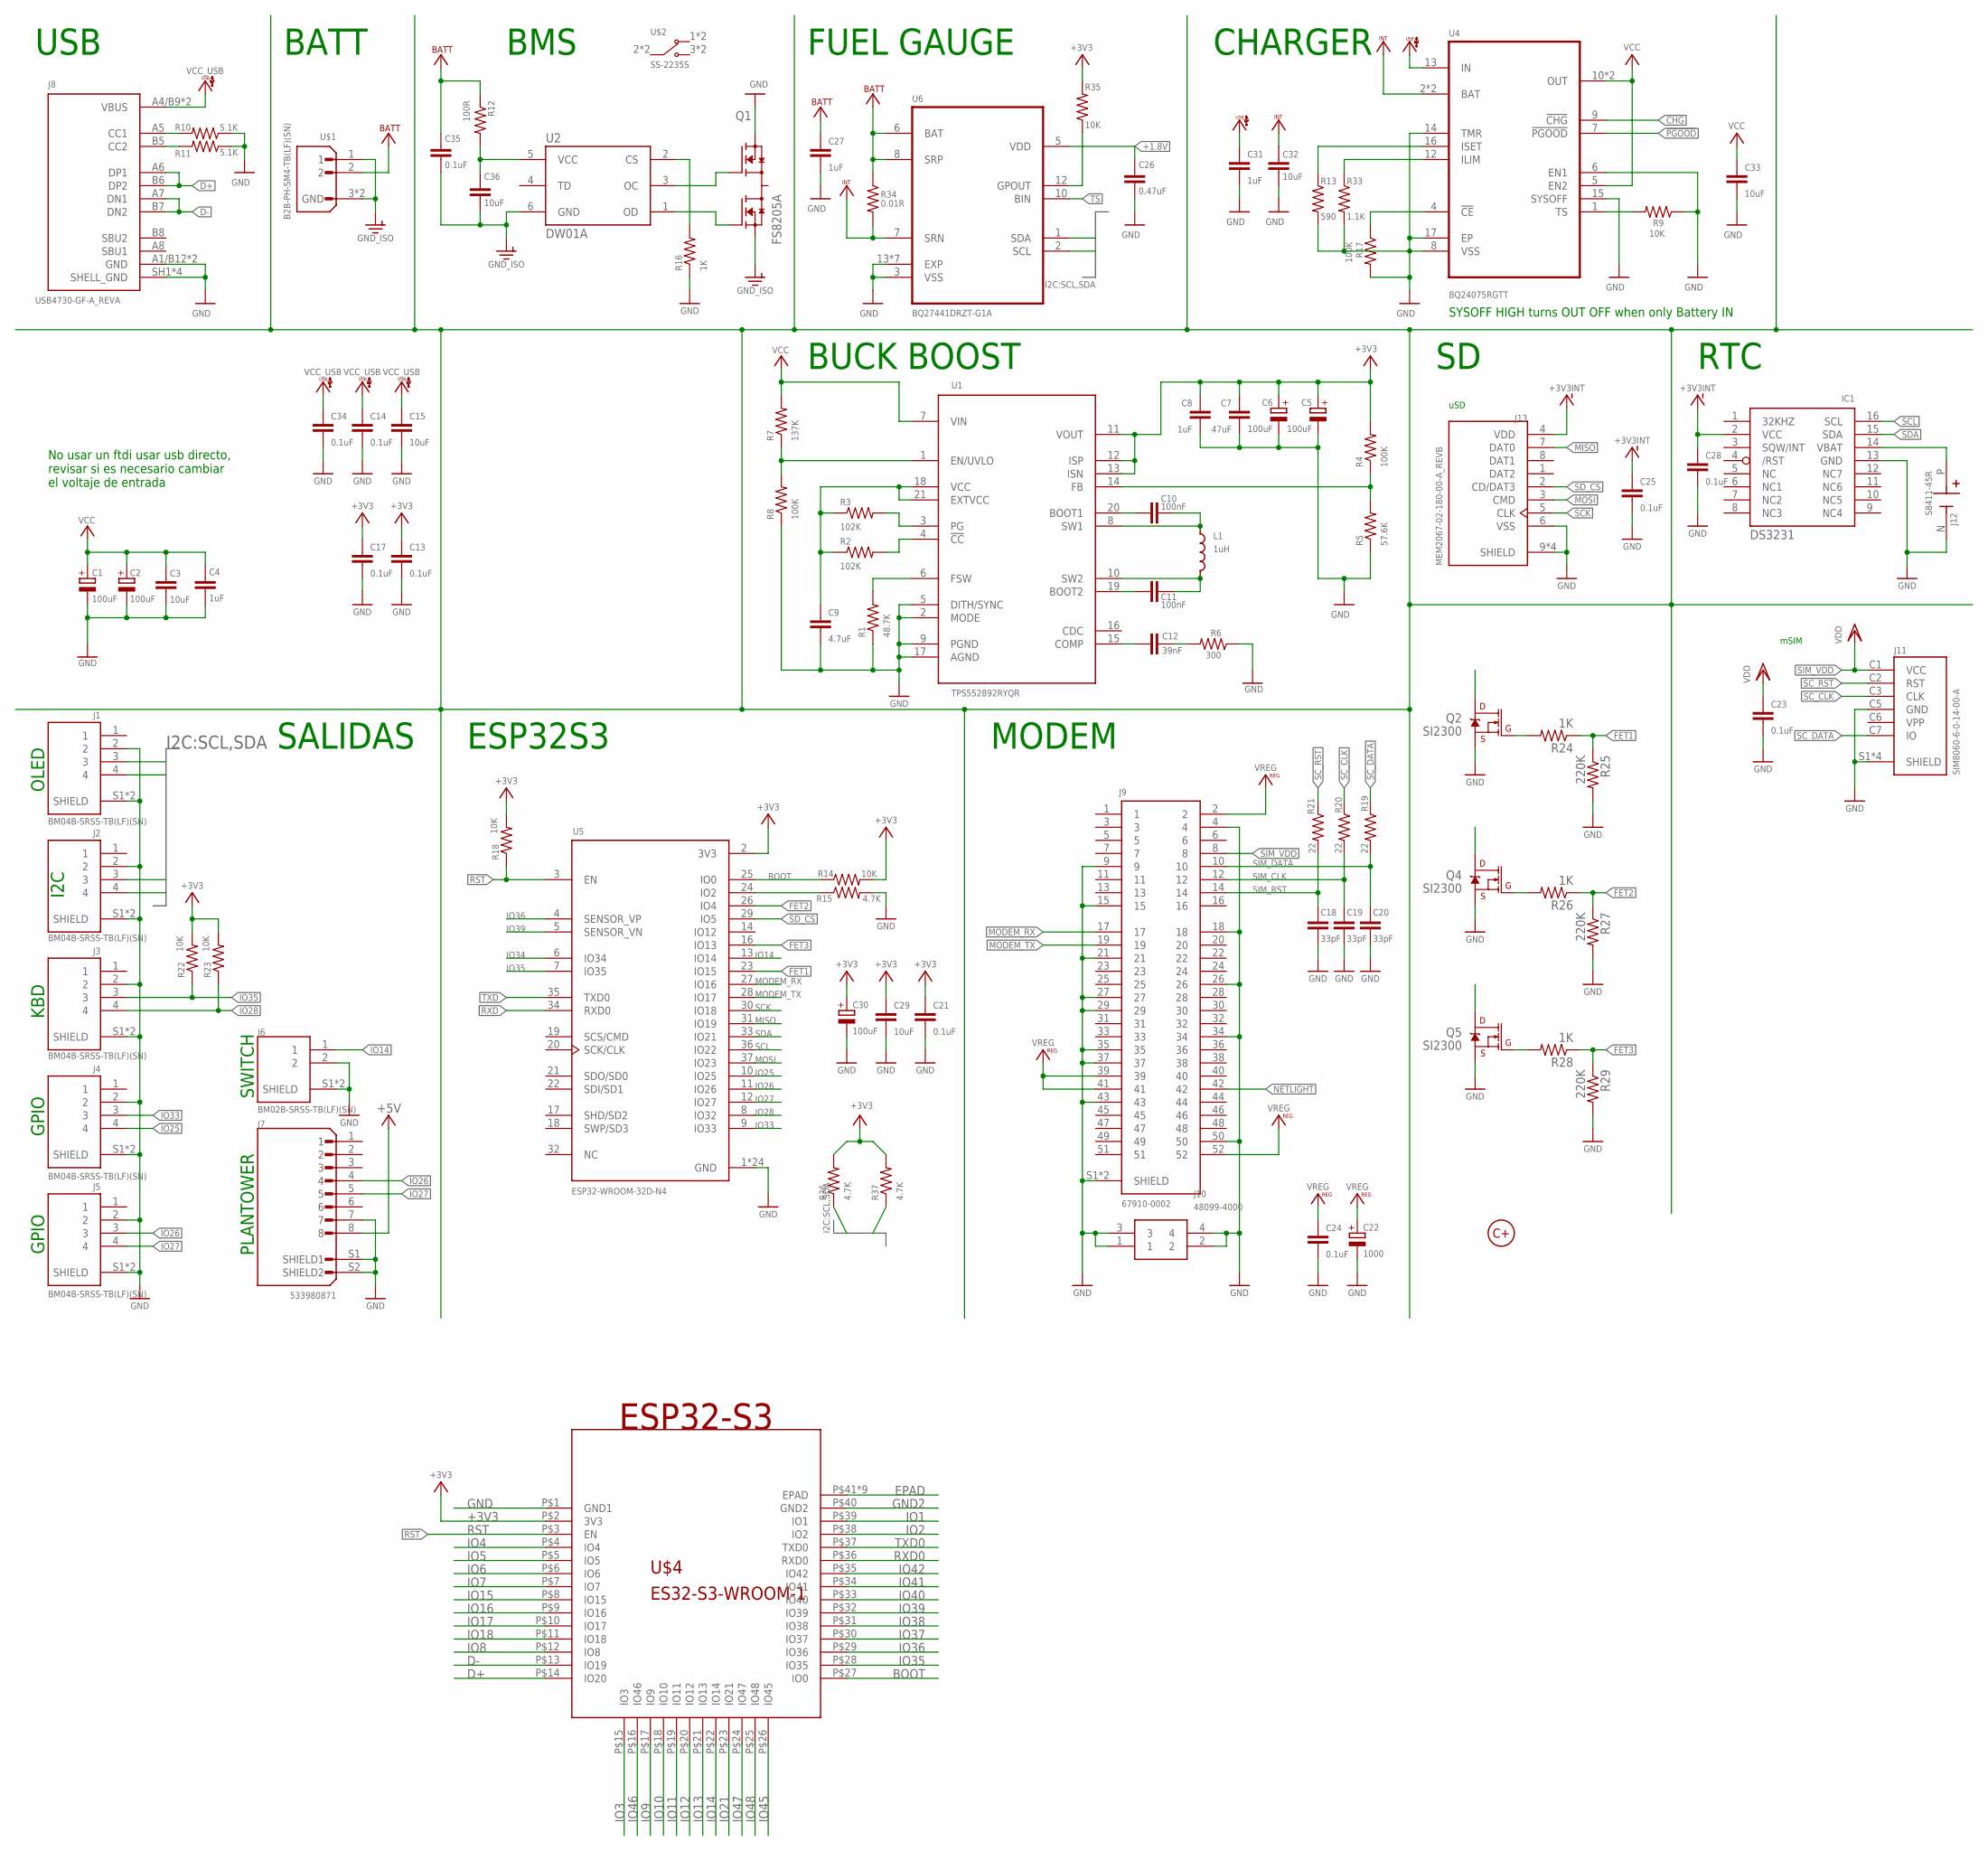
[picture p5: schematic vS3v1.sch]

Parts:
C1, C2, C5, C6: 100uF; SMC_B
C3, C15, C29, C32, C33, C36: 10uF; C0805
C4, C8, C27, C31: 1uF; C0805
C7: 47uF; C0805
C9: 4.7uF; C0805
C10, C11: 100nF; C0805
C12: 39nF; C0805
C13, C14, C17, C21, C23, C24, C25, C28, C34, C35: 0.1uF; C0805
C18, C19, C20: 33pF; C0805
C22: 1000; SMC_D
C26: 0.47uF; C0805
C30: 100uF; CT3528
IC1: DS3231/SO; SO16W
J1, J2, J3, J4, J5: BM04B-SRSS-TB(LF)(SN); JST_BM04B-SRSS-TB(LF)(SN)
J6: BM02B-SRSS-TB(LF)(SN); JST_BM02B-SRSS-TB(LF)(SN)
J7: 533980871; MOLEX_533980871
J8: USB4730-GF-A_REVA; GCT_USB4730-GF-A_REVA
J9: 67910-0002; MOLEX_67910-0002
J10: 48099-4000; 480994000
J11: SIM8060-6-0-14-00-A; GCT_SIM8060-6-0-14-00-A
J12: S8411-45R; HARWIN_S8411-45R
J13: MEM2067-02-180-00-A_REVB; GCT_MEM2067-02-180-00-A_REVB
L1: 1uH; IND_MDH7045C-220MA=P3
Q1: FS8205A; SOT95P280X145-6N
Q2, Q4, Q5: SI2300; SOT23-3
R1: 48.7K; R0805
R2, R3: 102K; R0805
R4, R8, R17: 100K; R0805
R5: 57.6K; R0805
R6: 300; R0805
R7: 137K; R0805
R9, R14, R18, R22, R23, R35: 10K; R0805
R10, R11: 5.1K; R0805
R12: 100R; R0805
R13: 590; R0805
R15, R36, R37: 4.7K; R0805
R16, R24, R26, R28: 1K; R0805
R19, R20, R21: 22; R0805
R25, R27, R29: 220K; R0805
R33: 1.1K; R0805
R34: 0.01R; R1206
U1: TPS552892RYQR; CONV_TPS552892RYQR
U2: DW01A; SOT23-6
U4: BQ24075RGTT; QFN50P300X300X100-17N
U5: ESP32-WROOM-32D-N4; MODULE_ESP32-WROOM-32D-N4
U6: BQ27441DRZT-G1A; IC_BQ27441DRZR-G1A
U$1: B2B-PH-SM4-TB(LF)(SN); JST_B2B-PH-SM4-TB(LF)(SN)
U$2: SS-2235S
U$3: LOGO_CMAS10MM; LOGO_10MM
U$4: ES32-S3-WROOM-1; ESP32-S3-WROOM-1

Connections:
!CHG: U4.9 (!CHG)
!PGOOD: U4.7 (!PGOOD)
+1.8V: C26.1, U6.5 (VDD)
+3V3: C5.+, C6.+, C7.1, C8.1, C13.1, C17.1, C21.1, C29.1, C30.+, R4.2, R14.2, R18.2, R22.2, R23.2, R35.2, R36.2, R37.2, U1.11 (VOUT), U1.12 (ISP), U1.13 (ISN), U5.2 (3V3), U$4.P$2 (3V3)
+3V3INT: C25.1, C28.1, IC1.2 (VCC), J13.4 (VDD)
+5V: J7.8
BOOT: R14.1, U5.25 (IO0), U$4.P$27 (IO0)
D+: J8.A6 (DP1), J8.B6 (DP2), U$4.P$14 (IO20)
D-: J8.A7 (DN1), J8.B7 (DN2), U$4.P$13 (IO19)
EPAD: U$4.P$41 (EPAD), U$4.P$42 (EPAD), U$4.P$43 (EPAD), U$4.P$44 (EPAD), U$4.P$45 (EPAD), U$4.P$46 (EPAD), U$4.P$47 (EPAD), U$4.P$48 (EPAD), U$4.P$49 (EPAD)
FET1: R24.1, R25.1, U5.23 (IO15)
FET2: R26.1, R27.1, U5.26 (IO4)
FET3: R28.1, R29.1, U5.16 (IO13)
GND: C1.-, C2.-, C3.2, C4.2, C5.-, C6.-, C7.2, C8.2, C9.2, C13.2, C14.2, C15.2, C17.2, C18.2, C19.2, C20.2, C21.2, C22.-, C23.2, C24.2, C25.2, C26.2, C27.2, C28.2, C29.2, C30.-, C31.2, C32.2, C33.2, C34.2, IC1.13 (GND), J1.2, J1.S1 (SHIELD), J1.S2 (SHIELD), J2.2, J2.S1 (SHIELD), J2.S2 (SHIELD), J3.2, J3.S1 (SHIELD), J3.S2 (SHIELD), J4.2, J4.S1 (SHIELD), J4.S2 (SHIELD), J5.2, J5.S1 (SHIELD), J5.S2 (SHIELD), J6.2, J6.S1 (SHIELD), J6.S2 (SHIELD), J7.7, J7.S1 (SHIELD1), J7.S2 (SHIELD2), J8.A1/B12 (GND), J8.B1/A12 (GND), J8.SH1 (SHELL_GND), J8.SH2 (SHELL_GND), J8.SH3 (SHELL_GND), J8.SH4 (SHELL_GND), J9.4, J9.9, J9.15, J9.18, J9.21, J9.26, J9.27, J9.29, J9.34, J9.35, J9.37, J9.43, J9.50, J9.S1 (SHIELD), J9.S2 (SHIELD), J10.1, J10.2, J10.3, J10.4, J11.C5 (GND), J11.S1 (SHIELD), J11.S2 (SHIELD), J11.S3 (SHIELD), J11.S4 (SHIELD), J12.N (-), J13.6 (VSS), J13.9 (SHIELD), J13.10 (SHIELD), J13.11 (SHIELD), J13.12 (SHIELD), Q1.3 (S2), Q2.2 (S), Q4.2 (S), Q5.2 (S), R1.1, R5.1, R6.1, R8.1, R9.1, R10.1, R11.1, R13.2, R15.2, R16.1, R17.2, R25.2, R27.2, R29.2, R33.2, U1.2 (MODE), U1.5 (DITH/SYNC), U1.9 (PGND), U1.17 (AGND), U4.6 (EN1), U4.8 (VSS), U4.14 (TMR), U4.15 (SYSOFF), U4.17 (EP), U5.1 (GND), U5.15 (GND), U5.38 (GND), U5.39_1 (GND), U5.39_2 (GND), U5.39_3 (GND), U5.39_4 (GND), U5.39_5 (GND), U5.39_6 (GND), U5.39_7 (GND), U5.39_8 (GND), U5.39_9 (GND), U5.39_10 (GND), U5.39_11 (GND), U5.39_12 (GND), U5.39_13 (GND), U5.39_14 (GND), U5.39_15 (GND), U5.39_16 (GND), U5.39_17 (GND), U5.39_18 (GND), U5.39_19 (GND), U5.39_20 (GND), U5.39_21 (GND), U6.3 (VSS), U6.13 (EXP), U6.14 (EXP), U6.15 (EXP), U6.16 (EXP), U6.17 (EXP), U6.18 (EXP), U6.19 (EXP), U$4.P$1 (GND1)
GND2: U$4.P$40 (GND2)
GND_ISO: C35.2, C36.2, Q1.1 (S1), U2.6 (GND), U$1.1, U$1.3 (GND), U$1.4 (GND)
GPOUT: R35.1, U6.12 (GPOUT)
IO1: U$4.P$39 (IO1)
IO2: U$4.P$38 (IO2)
IO3: U$4.P$15 (IO3)
IO4: U$4.P$4 (IO4)
IO5: U$4.P$5 (IO5)
IO6: U$4.P$6 (IO6)
IO7: U$4.P$7 (IO7)
IO8: U$4.P$12 (IO8)
IO9: U$4.P$17 (IO9)
IO10: U$4.P$18 (IO10)
IO11: U$4.P$19 (IO11)
IO12: U$4.P$20 (IO12)
IO13: U$4.P$21 (IO13)
IO14: J6.1, U5.13 (IO14), U$4.P$22 (IO14)
IO15: U$4.P$8 (IO15)
IO16: U$4.P$9 (IO16)
IO17: U$4.P$10 (IO17)
IO18: U$4.P$11 (IO18)
IO21: U$4.P$23 (IO21)
IO25: J4.4, U5.10 (IO25)
IO26: J5.3, J7.4, U5.11 (IO26)
IO27: J5.4, J7.5, U5.12 (IO27)
IO28: J3.4, R23.1, U5.8 (IO32)
IO33: J4.3, U5.9 (IO33)
IO34: U5.6 (IO34)
IO35: J3.3, R22.1, U5.7 (IO35), U$4.P$28 (IO35)
IO36: U5.4 (SENSOR_VP), U$4.P$29 (IO36)
IO37: U$4.P$30 (IO37)
IO38: U$4.P$31 (IO38)
IO39: U5.5 (SENSOR_VN), U$4.P$32 (IO39)
IO40: U$4.P$33 (IO40)
IO41: U$4.P$34 (IO41)
IO42: U$4.P$35 (IO42)
IO45: U$4.P$26 (IO45)
IO46: U$4.P$16 (IO46)
IO47: U$4.P$24 (IO47)
IO48: U$4.P$25 (IO48)
MISO: J13.7 (DAT0), U5.31 (IO19)
MODEM_RX: J9.17, U5.27 (IO16)
MODEM_TX: J9.19, U5.28 (IO17)
MOSI: J13.3 (CMD), U5.37 (IO23)
unnamed: R2.2, U1.4 (!CC)
unnamed: C12.1, U1.15 (COMP)
unnamed: C12.2, R6.2
unnamed: R1.2, U1.6 (FSW)
unnamed: R3.2, U1.3 (PG)
unnamed: C9.1, R2.1, R3.1, U1.18 (VCC), U1.21 (EXTVCC)
unnamed: R4.1, R5.2, U1.14 (FB)
unnamed: C11.2, L1.2, U1.10 (SW2)
unnamed: C10.1, U1.20 (BOOT1)
unnamed: C10.2, L1.1, U1.8 (SW1)
unnamed: C11.1, U1.19 (BOOT2)
unnamed: R7.1, R8.2, U1.1 (EN/UVLO)
unnamed: J8.A5 (CC1), R10.2
unnamed: J8.B5 (CC2), R11.2
unnamed: Q1.4 (G2), U2.3 (OC)
unnamed: Q1.6 (G1), U2.1 (OD)
unnamed: C36.1, R12.2, U2.5 (VCC)
unnamed: IC1.14 (VBAT), J12.P (+)
unnamed: R9.2, U4.1 (TS)
unnamed: R13.1, U4.16 (ISET)
unnamed: R33.1, U4.12 (ILIM)
unnamed: R15.1, U5.24 (IO2)
unnamed: R16.2, U2.2 (CS)
unnamed: R17.1, U4.4 (!CE)
unnamed: Q2.1 (G), R24.2
unnamed: Q4.1 (G), R26.2
unnamed: Q5.1 (G), R28.2
NETLIGHT: J9.42
RST: R18.1, U5.3 (EN), U$4.P$3 (EN)
RXD: U5.34 (RXD0)
RXD0: U$4.P$36 (RXD0)
SCK: J13.5 (CLK), U5.30 (IO18)
SCL: IC1.16 (SCL), J1.4, J2.4, R37.1, U5.36 (IO22), U6.2 (SCL)
SC_CLK: J11.C3 (CLK), R20.1
SC_DATA: J11.C7 (IO), R19.1
SC_RST: J11.C2 (RST), R21.1
SDA: IC1.15 (SDA), J1.3, J2.3, R36.1, U5.33 (IO21), U6.1 (SDA)
SD_CS: J13.2 (CD/DAT3), U5.29 (IO5)
SIM_CLK: C19.1, J9.12, R20.2
SIM_DATA: C20.1, J9.10, R19.2
SIM_RST: C18.1, J9.14, R21.2
SIM_VDD: C23.1, J9.8, J11.C1 (VCC)
TS: U6.10 (BIN)
TXD: U5.35 (TXD0)
TXD0: U$4.P$37 (TXD0)
VBAT: C27.1, C35.1, R12.1, R34.1, U6.6 (BAT), U6.8 (SRP), U$1.2
VCC: C1.+, C2.+, C3.1, C4.1, C33.1, R7.2, U1.7 (VIN), U4.5 (EN2), U4.10 (OUT), U4.11 (OUT)
VCCINT: C32.1, R34.2, U4.2 (BAT), U4.3 (BAT), U6.7 (SRN)
VCC_USB: C14.1, C15.1, C31.1, C34.1, J8.A4/B9 (VBUS), J8.B4/A9 (VBUS), U4.13 (IN)
VREG: C22.+, C24.1, J9.2, J9.39, J9.41, J9.52

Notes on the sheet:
RTC
mSIM
uSD
SYSOFF HIGH turns OUT OFF when only Battery IN
USB
BATT
BMS
FUEL GAUGE
CHARGER
SWITCH
OLED
I2C
KBD
GPIO
BUCK BOOST
SALIDAS
ESP32S3
MODEM
PLANTOWER
No usar un ftdi usar usb directo, revisar si es necesario cambiar el voltaje de entrada

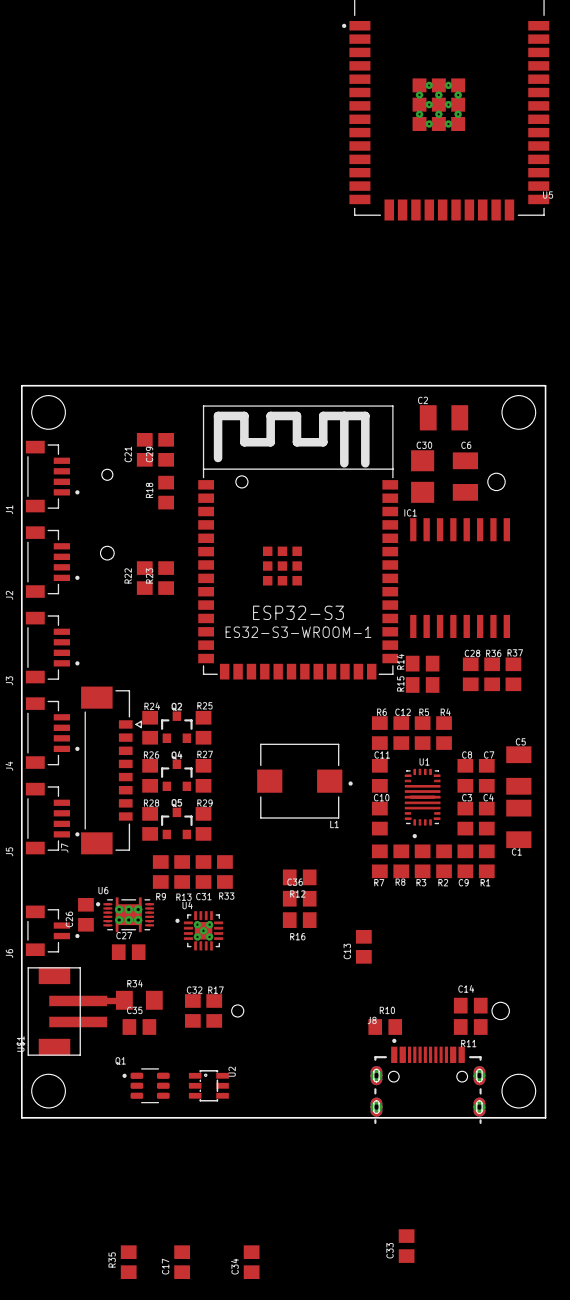
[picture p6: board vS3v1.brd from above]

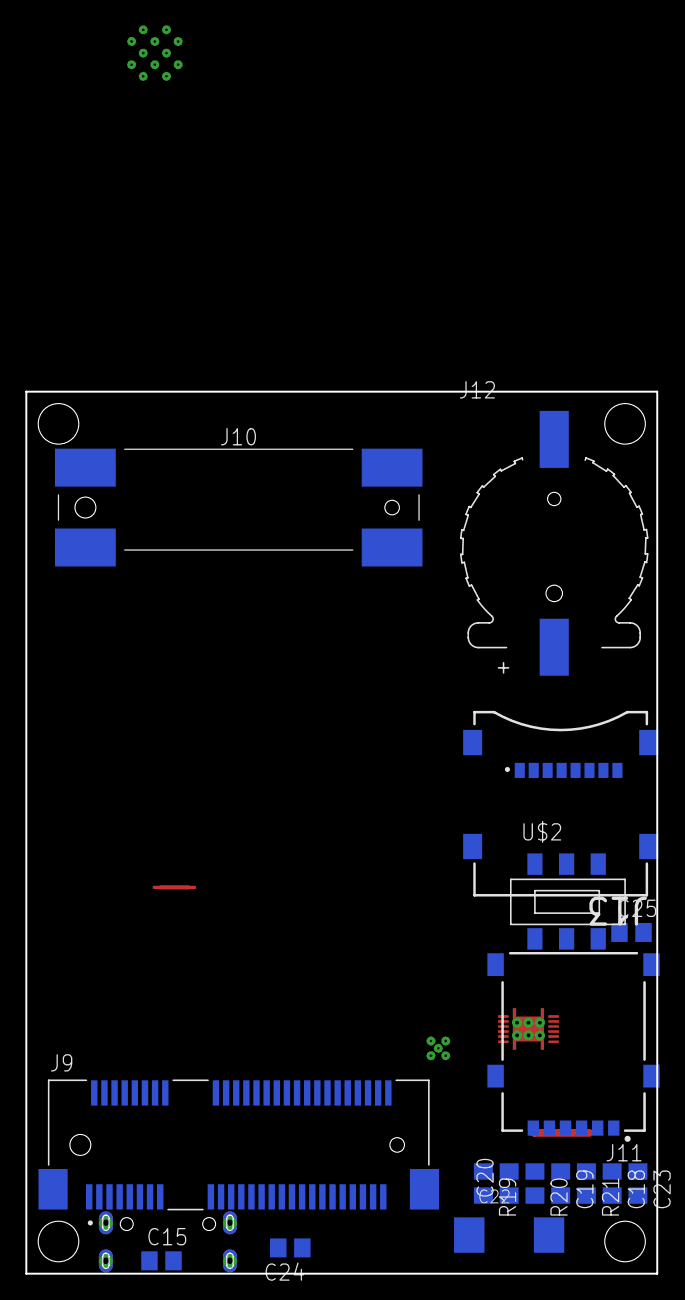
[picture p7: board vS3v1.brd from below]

Board: 2 copper layers, 49.8 x 69.6 mm, 97 parts (17 on the bottom side), 70 nets.

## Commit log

2026-01-18 Add datasheet link for ESP32-WROOM-32 S3
    Updated the ESP32-WROOM-32 S3 entry to include a link to its datasheet.
2026-01-18 feat: Add initial PCB design, schematic, and datasheet for miniMadre.
    [vS3v1.brd, vS3v1.sch]
2026-01-18 Save local changes (PCB update, PDF remove)
    [vS3v1.sch]

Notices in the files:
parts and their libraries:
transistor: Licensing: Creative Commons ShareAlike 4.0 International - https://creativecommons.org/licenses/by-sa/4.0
